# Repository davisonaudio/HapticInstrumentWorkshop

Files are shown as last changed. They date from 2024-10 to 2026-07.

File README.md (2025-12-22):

# HaptiCoupler System

This repository contaisn the design files and firmware for the HaptiCoupler system.
It also contains information for the Haptic instrument study that used the HaptiCoupler system to explore digital musical instrument designs.

More information about the system can be found in the Wiki tab of this repo.

The HaptiCoupler is a device that enables simultaneous tactile sensing and haptic feedback through a signle voice coil transducer.

This is achieved by actuating the voice coil with a voltage and sensing with current, along with some DSP running on the Teensy 4.0 to cancel the actuation signal from the sensing signal.

It is designed primarily for use with audio-driven digital resonator instruments, though can be used for other purposes.

# HapticInstrumentWorkshop
Information for the self-sensing vibrotactile haptic instrument design project. Part of the Augmented Instruments Lab at Imperial College London

For more information on using the kit and detailed documentation, visit the [wiki](https://github.com/davisonaudio/HapticInstrumentWorkshop/wiki).

Access the web control panel [here](https://davisonaudio.github.io/HapticInstrumentWorkshop/) for logging information and parameter adjustment.

# Kit Contents

- 1x Teensy 4.0 Microcontroller development board with headers
- 1x custom amplifier PCB (using MAX98789 amplifier)
- 1x Dayton Audio EX32VBDS-4 Voice Coil Transducer
- 1x 9V DC 5.1mm barrel jack power supply (centre-positive)
- 1x USB A to micro USB cable

# Getting Started
The Teensy 4.0 will come preloaded with the required firmware and mounted with its headers onto the top of the amplifier board. 

# Cloning the repo
To get a local copy of this repository (for editing the firmware or hardware files included), run the following command:
> git clone --recurse-submodules https://github.com/davisonaudio/HapticInstrumentWorkshop.git

This will clone the main repo as well as the audio-utils submodule within the firmware folder.

# Hacking the Hardware

It is unlikely that the PCB is something that we be modified as part of this study. For those with sufficient electronics knowledge, however, the design files (schematic and PCB PDFs along with KiCAD files) can be found in the hardware folder of this repo.

# Hacking the Example Software

# Hacking the Firmware
For advanced users, the firmware running on the Teensy can be modified and recompiled. All of the required files are within the firmware folder of this repo.

The firmware is developed for the Teensy using [PlatformIO](https://platformio.org). This provides more flexibility than using the Arduino IDE (as is often used with Teensy and similar boards), but still allows use of the Teensy system's wide array of useful C++ libraries. It also avoids the increased complexities of utilising a proper embedded development environment (such as NXP's MCUXpresso for the Teensy 4.0's NXP RT1060 microcontroller).

Visual Studio Code is required for PlatformIO development. For further details of development environment setup please refer to the wiki.

# Publications
For more information on related research output of this project, please refer to the below publications:

- M. Davison, C. J. Webb, M. Ducceschi and A. P. McPherson. A self-sensing haptic actuator for tactile interaction with physical modelling synthesis. *Proc. International Conference on New Interfaces for Musical Expression (NIME)*, Utrecht, Netherlands. 2024. [PDF](http://instrumentslab.org/data/andrew/davison_nime2024.pdf)

- M. Davison and A. P. McPherson. A self-sensing vibrotactile transducer for bidirectional interaction. *Proc. Eurohaptics* (work in progress), Lille, France. 2024. [PDF](http://instrumentslab.org/data/andrew/davison_eurohaptics2024.pdf)

# Contributors
This project is developed and maintained by Matt Davison. Massive thank you also to the additional contributors who helped this project happen:

- Anna Silver - CAD design of 3D printed elements
- David Gong - Initial PCB design and firmware bring-up of the amplifier board
- Prof. Andrew McPherson - Supervision and guidance throughout

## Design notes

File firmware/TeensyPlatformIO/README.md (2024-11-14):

# Self Sensing Haptic Transducer Teensy

Based on this repo: https://github.com/davisonaudio/self-sensing-haptic-transducer/tree/main
Ported from Bela to teensy

# To Use
- Set up platformio environment locally. See here for instructions: https://github.com/dsgong/max98389_teensy
- Measure the impedance of the voice coil you are using and obtain a digital filter that models the admittance response. Change these values in main.cpp.
- Upload to teensy.

# Hardware
The setup shown in this project consists of the following hardware:

- Teensy 4.0 or 4.1
- Audio amplifier with current and voltage sense feedback via i2s. I used the max98389 amplifier.
- A voice coil actuator - this project should work with many VCAs, surface transducer style VCAs (designed to turn a surface into a speaker) are what have primarily been used for testing. The default filter values correspond to a DAEX25Q-4. 
- See schematic.pdf for an example schematic

# MIDI Control

# EEPROM
The Teensy 4.0 has 1080 bytes of EEPROM memory available. This is used in this project to store tuning parameters to enable persistence after a power cycle.

The parameters are saved to EEPROM when the device receives a "Store to EEPROM" MIDI message (see MIDI documentation for more info).

The EEPROM values are loaded at the beginning of the firmware programme.

Each value is stored as a 32 bit value across 4 consecutive bytes, using little-endianness - i.e. the LSB of the value will be at EEPROM address n+0 with the MSB at address n+3.

## EEPROM Address Map

| Base Address | Parameter | Channel Num | Units | Notes |
| --- | --- | --- | ----- | ----- |
| Resonant Frequency | | 1 | | |
| Peak Gain | | 2 | | |
| Resonance Q | | 3 | | |
| Tone Level | | 4 | | |
| | | | | |
| | | | | |
| | | | | |
| | | | | |
| | | | | |
| | | | | |

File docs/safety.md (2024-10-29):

Please read the following information carefully before powering on or using the supplied hardware kit. Though the kit operates on a low voltage DC supply (5-10V, 9V when using the supplied power adapter) is it still important to adhere to basic electrical safety principles. Please keep these in mind when using the hardware kit.
# Basic Operating Procedure
- Double check any circuits before powering up the system (check for any obvious shorts or erroneously connected wires)
- Remove power from the system before making any changes to the circuitry
- Keep all elements of the hardware kit away from any liquids
- Use a 5-10V DC power supply (centre-positive) when powering the amplifier such as the provided 9V adapter. Do not use power supplies with voltages outside this range.
- Do not leave the hardware powered on while unattended
- Do not place any part of the kit on any conductive surface
- Avoid connecting headphones, or any transducer that is subsequently placed close to the ear, to the output of the amplifier to avoid sound pressure levels that exceed safe limits

# Safety Mitigations
- The amplifier IC (MAX98789) has inbuilt output short protection to prevent damage from the speaker terminals being shorted together
- The PCB has built in protection (Schottky diode) to prevent damage if a power supply with inverted polarity is plugged in
- The maximum voltage used on the board is 9V DC – no high voltages are used.
- The power supply included with the kit is CE marked and a class II mains powered device (isolated).

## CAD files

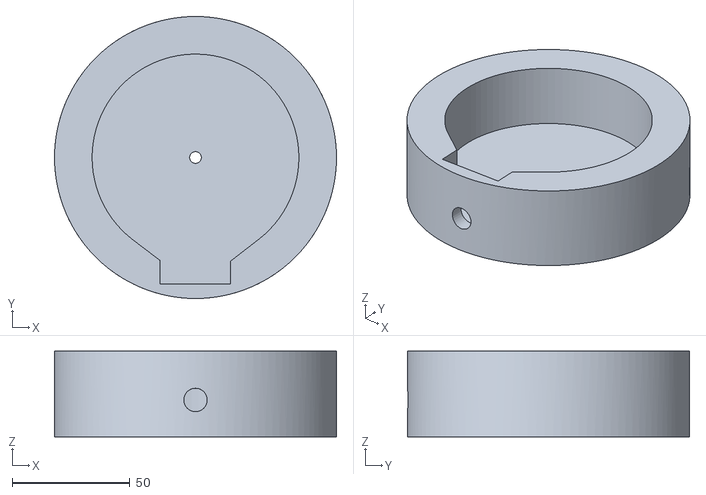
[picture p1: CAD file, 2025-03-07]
hardware/3D_printing_files/Actuator_Base.stl
120.0 x 120.0 x 36.5

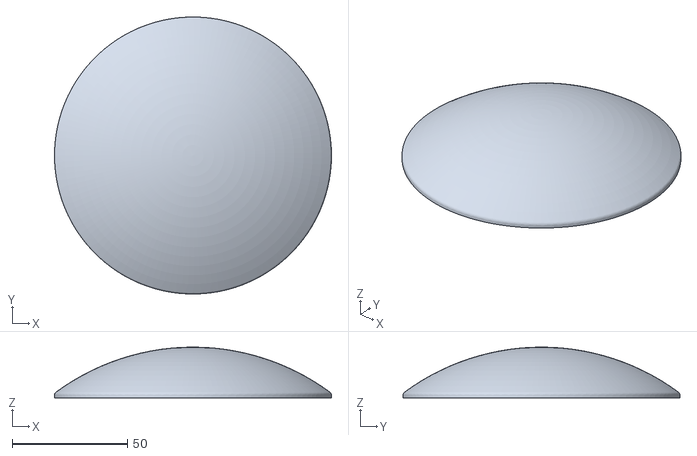
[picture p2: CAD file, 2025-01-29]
hardware/3D_printing_files/Other more niche parts/02-07_A1_ButtonTop.stl
120.0 x 120.0 x 22.0

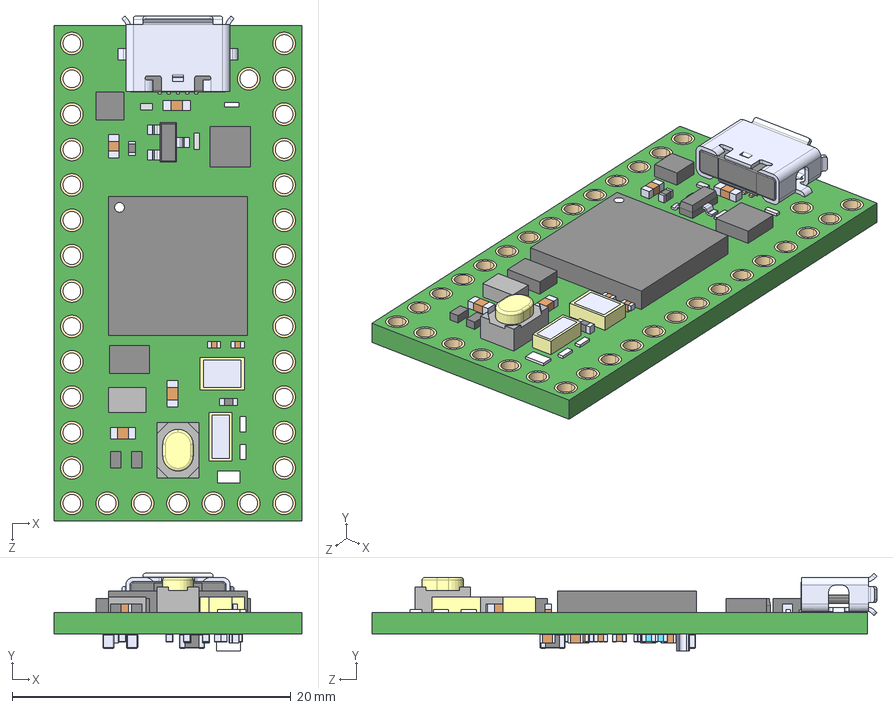
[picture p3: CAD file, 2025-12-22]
hardware/kicad_project/DEV-15583/DEV-15583.step
17.8 x 5.58 x 36.3 mm
DEV-15583 board
C5-C18 (0.55mm)
C20-C24 (0.65)
R1-R3 (0.4inch)_1269AS-H-3R3M=P2
L1^DEV-15583 ASS
C x 2
C2

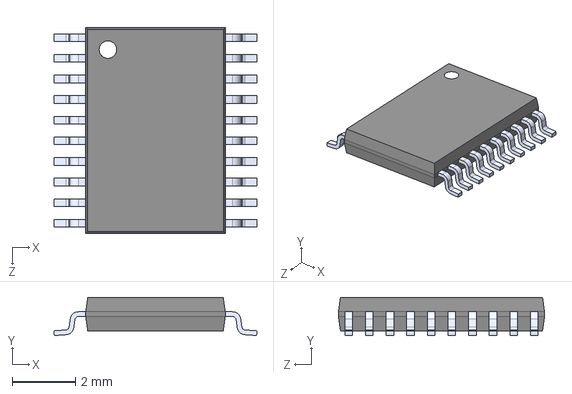
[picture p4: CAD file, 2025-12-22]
hardware/kicad_project/TXS0108EPWR/TXS0108EPWR.step
6.40 x 1.20 x 6.50 mm

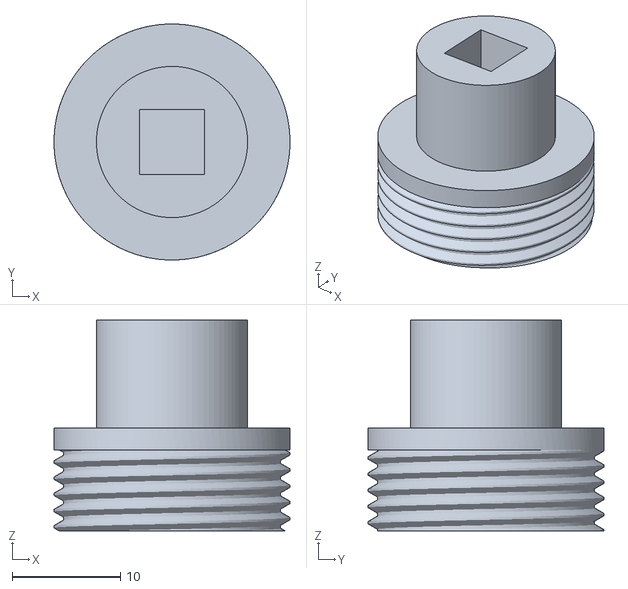
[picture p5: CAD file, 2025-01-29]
hardware/3D_printing_files/Other more niche parts/26-06_A1_universal_adapter.stl
21.8 x 21.8 x 19.5

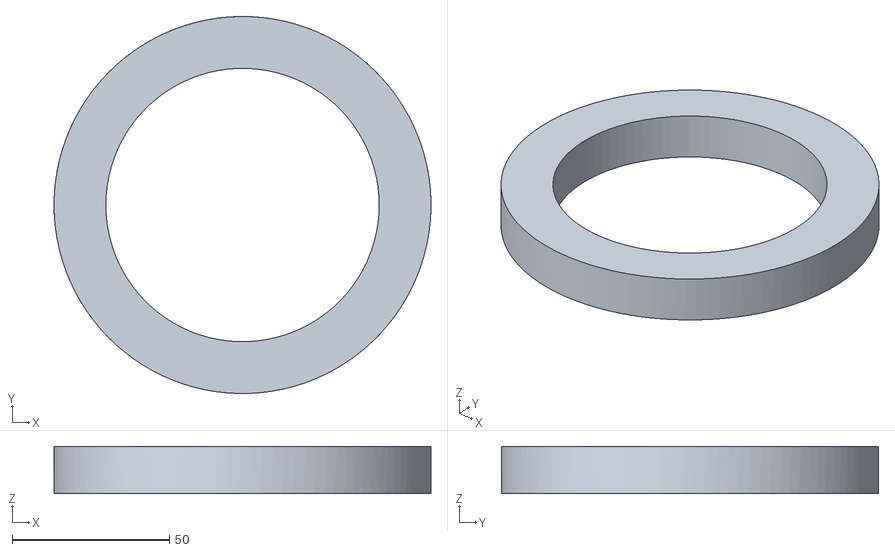
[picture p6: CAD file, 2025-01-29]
hardware/3D_printing_files/Other more niche parts/21-06_A1_SecureRing.stl
120.0 x 120.0 x 15.0

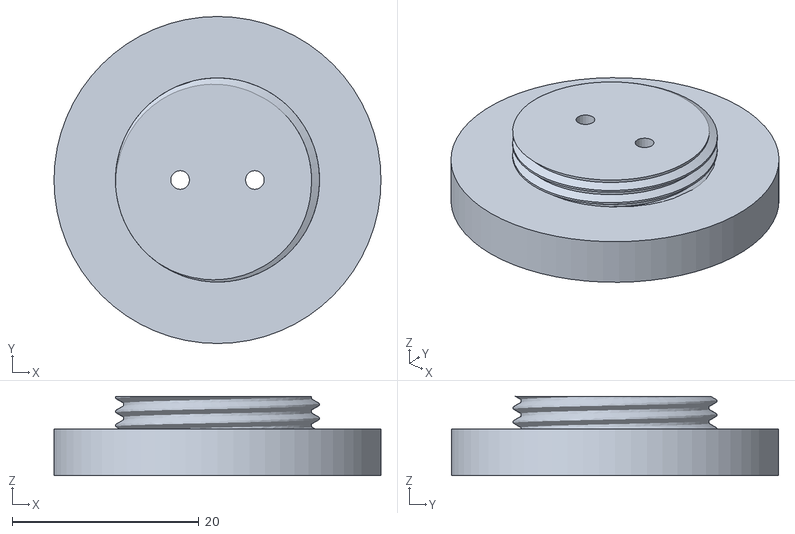
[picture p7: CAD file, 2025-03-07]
hardware/3D_printing_files/screwtop_rev_b.stl
35.0 x 35.0 x 8.50

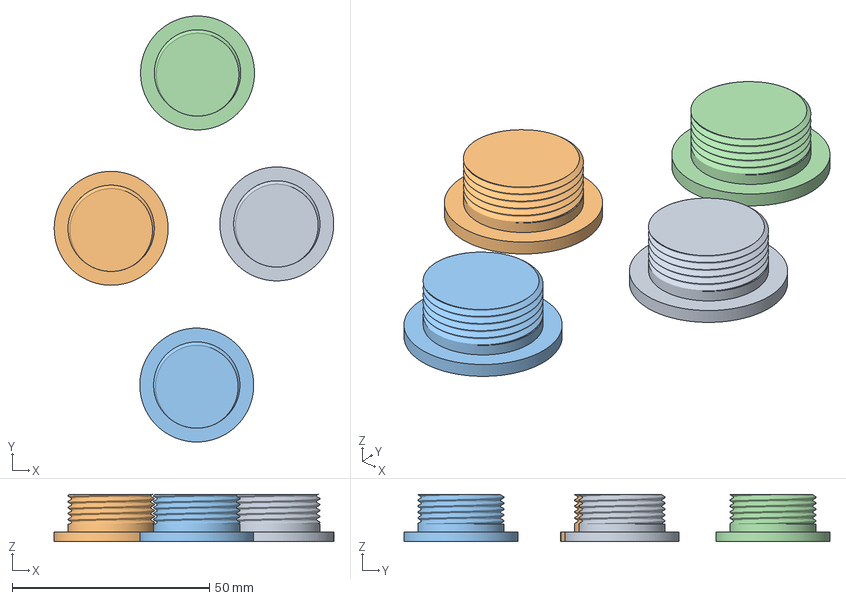
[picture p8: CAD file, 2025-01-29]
hardware/3D_printing_files/Other more niche parts/screw_top_Large_Actuator_x4.3mf
70.8 x 107.9 x 12.0 mm
screw_top_Large_Actuator.stl x 4

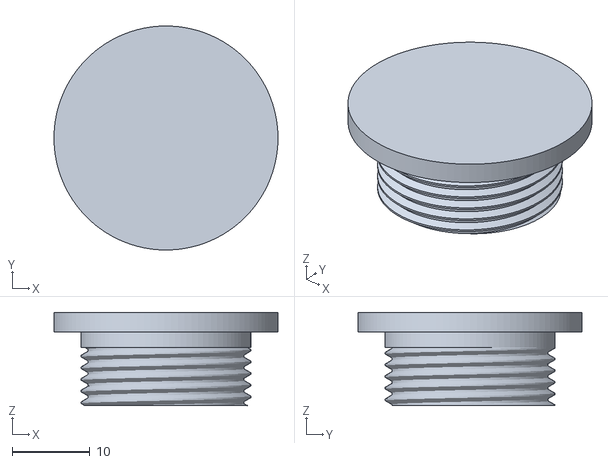
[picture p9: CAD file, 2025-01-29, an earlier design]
hardware/3D_printing_files/screwtop_rev_a.stl
28.8 x 28.8 x 12.0

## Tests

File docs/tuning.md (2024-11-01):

# Tuning

The filters used for cancellation of the actuation signal, and frequency used for damping sensing, are dependant upon the mechanical properties of the actuator.

These properties change when objects are mounted on top of the actuator (or when the actuator itself is mounted to different objects)

This may mean that the tuning parameters need adjusting after changing the mechanical properties of the instrument.

To retune the cancellation filtering, MIDI commands can be send to the device. See the midi documentation for how to do this.

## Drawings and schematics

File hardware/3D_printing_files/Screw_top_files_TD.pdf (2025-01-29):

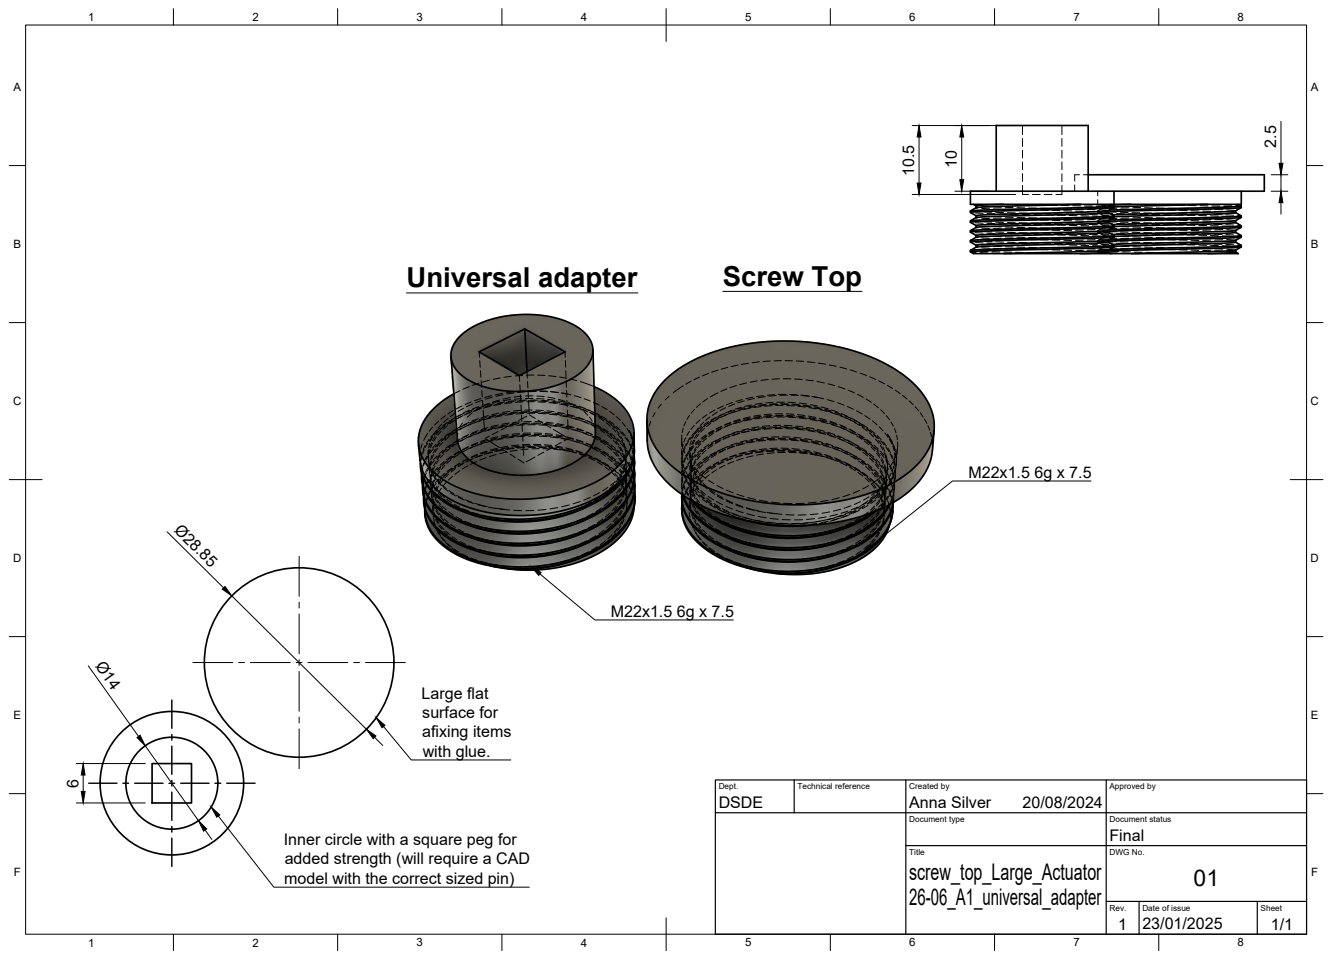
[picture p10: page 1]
Title; DWG No.; Rev.; Date of issue; Sheet; Large flat surface for afixing items with glue.; Universal adapter; Screw Top

Dept. DSDE | Technical reference | Created by Anna Silver 20/08/2024 | Approved by

Document type | Document status Final

Inner circle with a square peg for
added strength (will require a CAD
model with the correct sized pin)

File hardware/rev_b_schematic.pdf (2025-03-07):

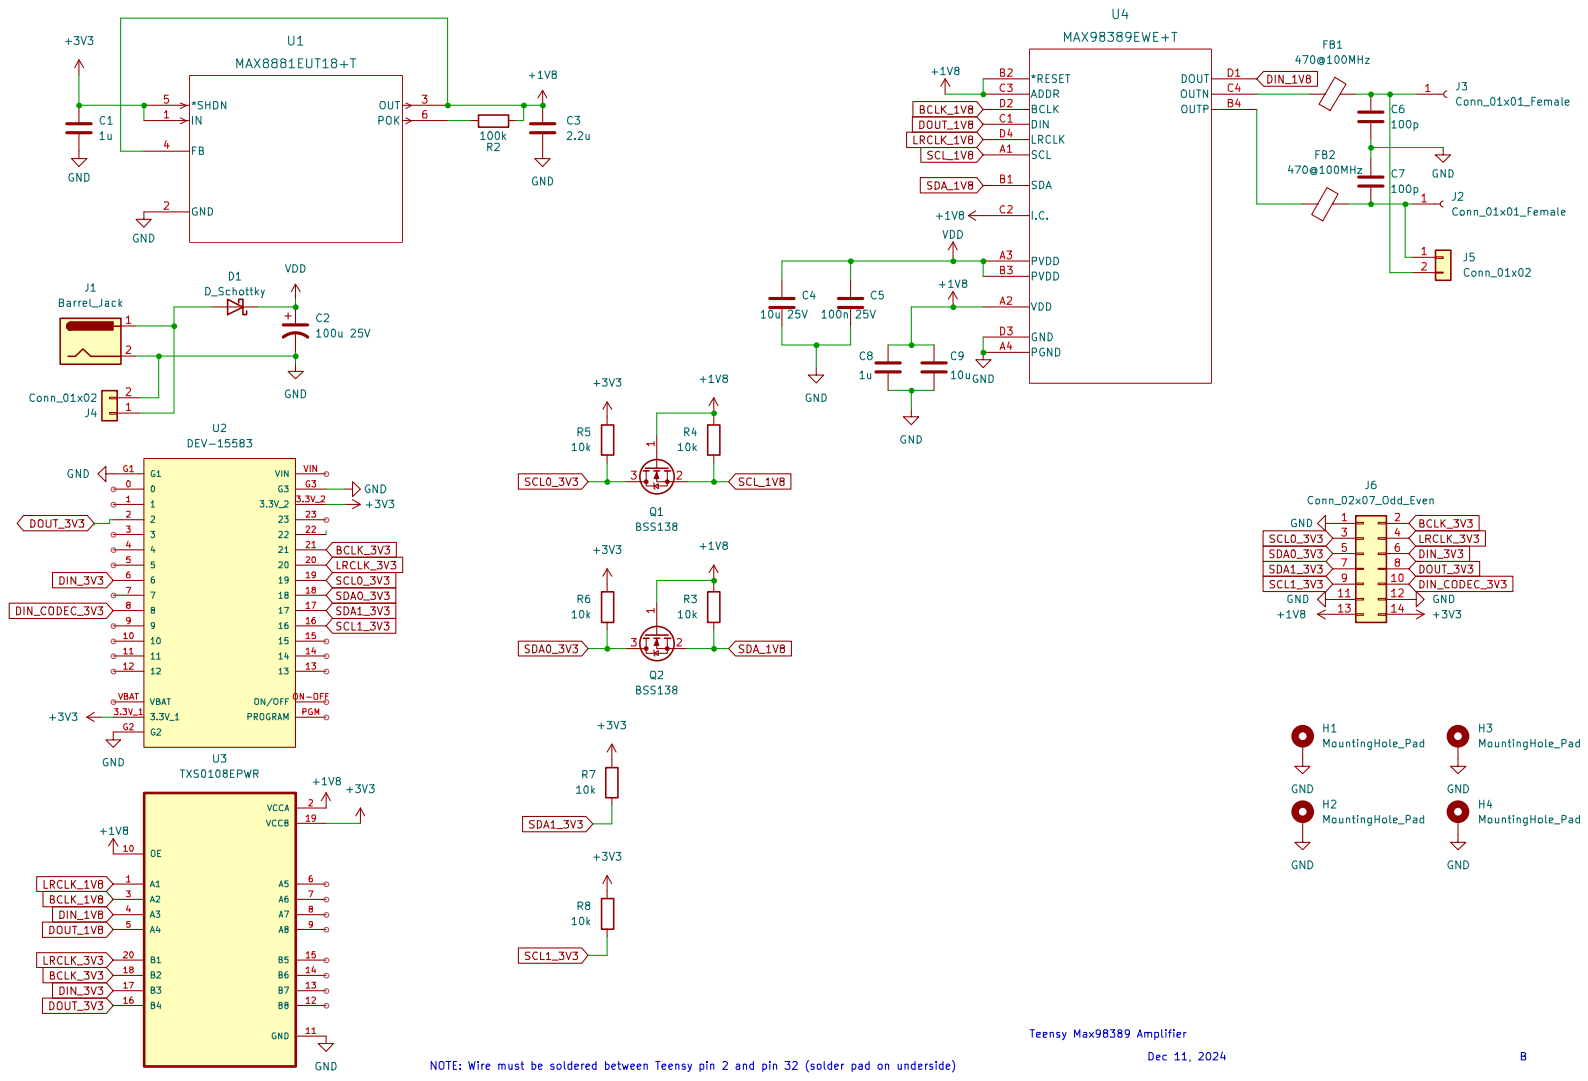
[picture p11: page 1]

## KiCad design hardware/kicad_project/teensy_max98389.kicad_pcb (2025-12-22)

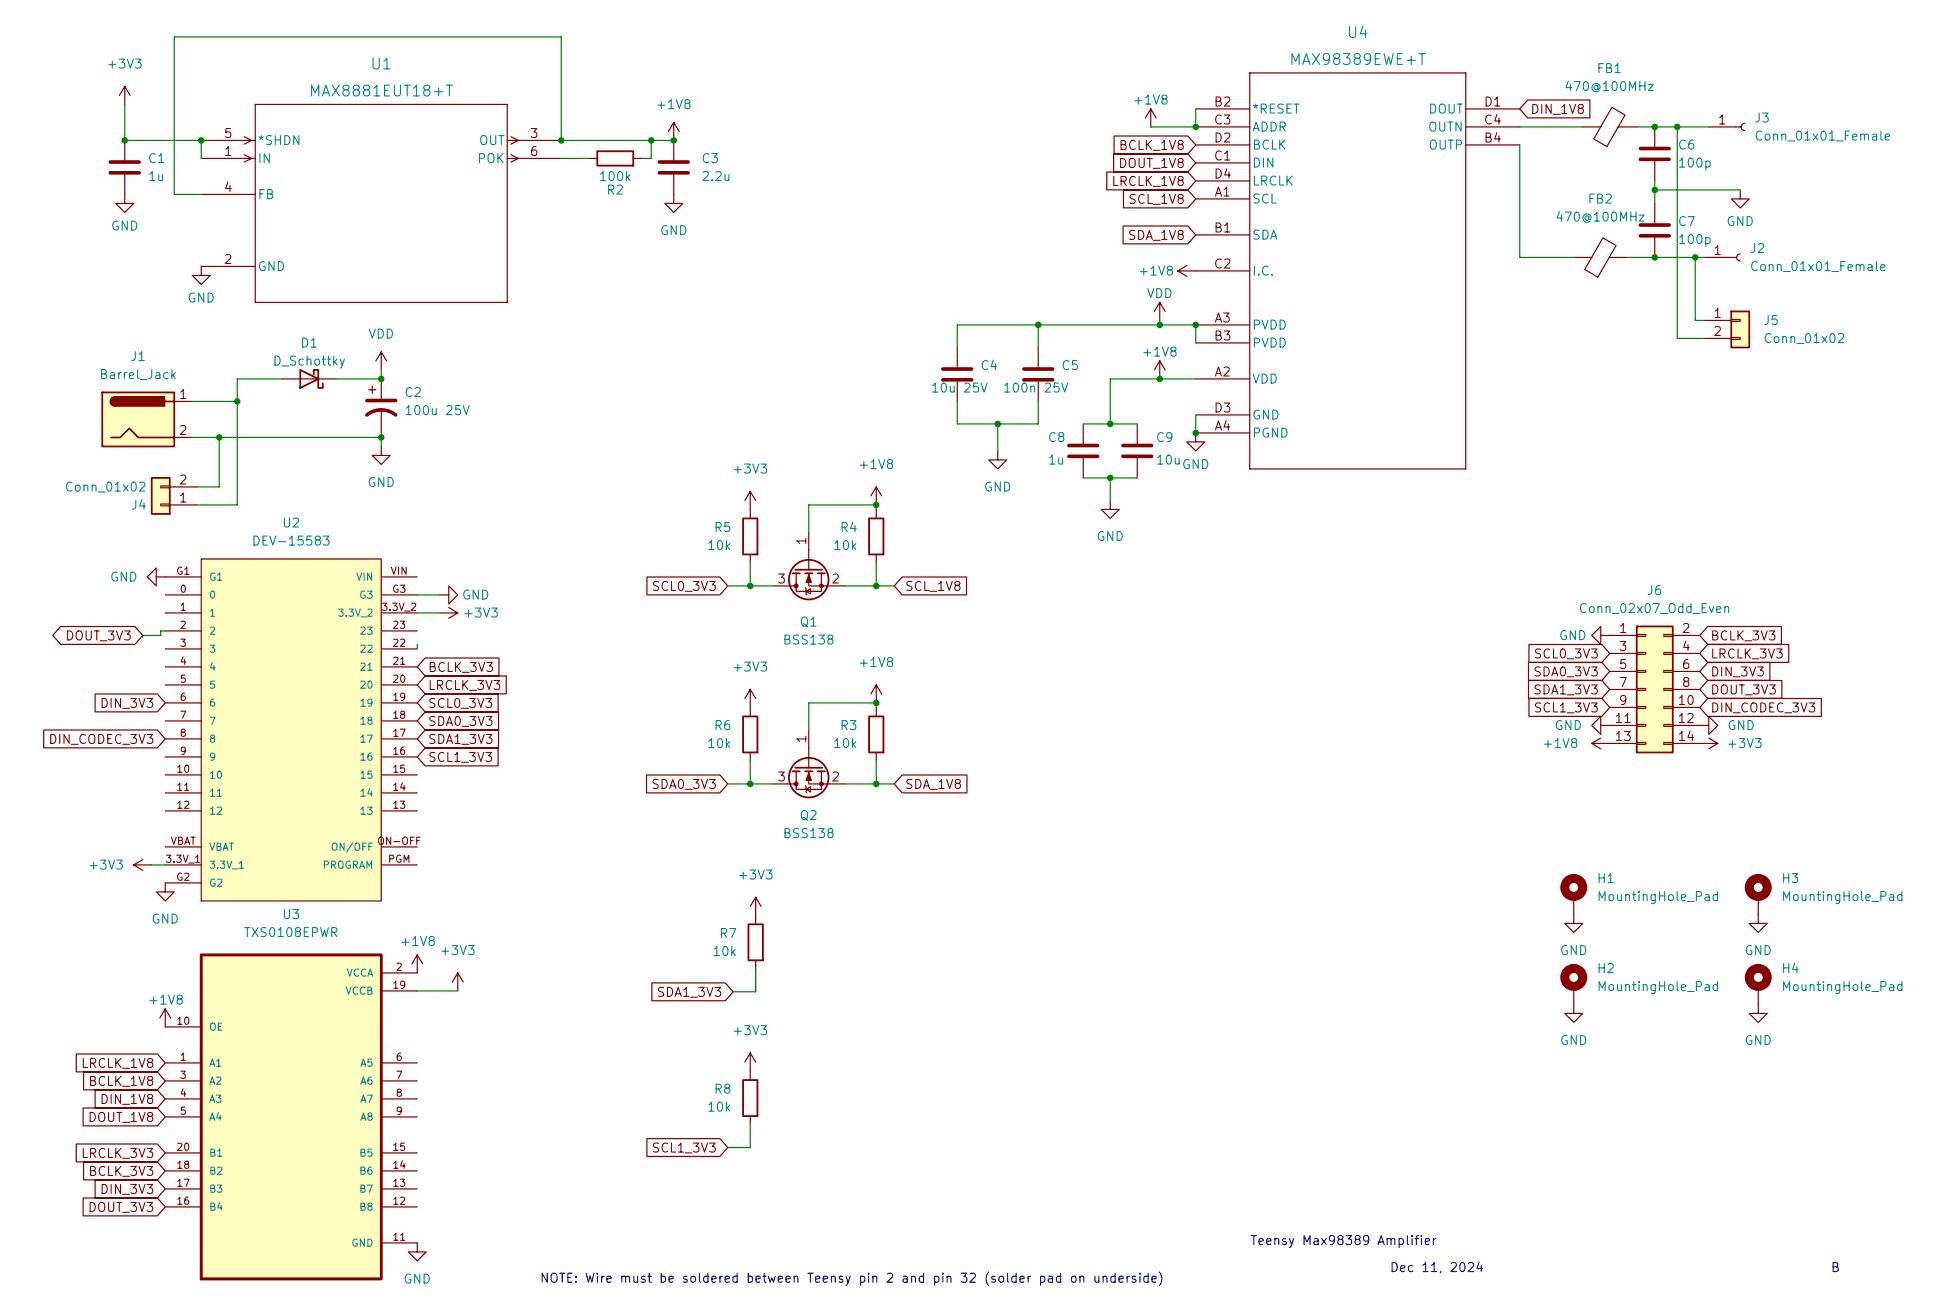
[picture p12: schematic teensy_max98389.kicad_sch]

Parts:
C1, C8: 1u; C_0603_1608Metric
C2: 100u 25V; CP_Radial_D6.3mm_P2.50mm
C3: 2.2u; C_0603_1608Metric
C4: 10u 25V; C_0603_1608Metric
C5: 100n 25V; C_0603_1608Metric
C6, C7: 100p; C_0603_1608Metric
C9: 10u; C_0603_1608Metric
D1: D_Schottky; D_0603_1608Metric
FB1, FB2: 470@100MHz; L_0805_2012Metric
H1, H2, H3, H4: MountingHole_Pad; MountingHole_3.2mm_M3_DIN965_Pad_TopBottom
J1: Barrel_Jack; BarrelJack_Kycon_KLDX-0202-xC_Horizontal
J2, J3: Conn_01x01_Female; MountingHole_6.4mm_M6_DIN965_Pad
J4, J5: Conn_01x02; Molex_KK-254_AE-6410-02A_1x02_P2.54mm_Vertical
J6: Conn_02x07_Odd_Even; PinHeader_2x07_P2.54mm_Vertical
Q1, Q2: BSS138; SOT-23
R2: 100k; R_0603_1608Metric
R3, R4, R5, R6, R7, R8: 10k; R_0603_1608Metric
U1: MAX8881EUT18+T; 21-0058I_MXM
U2: DEV-15583; MODULE_DEV-15583
U3: TXS0108EPWR; SOP65P640X120-20N
U4: MAX98389EWE+T; 21-100636_ADI

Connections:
+1V8: C3.1, C8.1, C9.1, J6.13, Q1.1 (G), Q2.1 (G), R2.2, R3.1, R4.1, U1.3 (OUT), U1.4 (FB), U3.2 (VCCA), U3.10 (OE), U4.A2 (VDD), U4.B2 (*RESET), U4.C2 (I.C.), U4.C3 (ADDR)
+3V3: C1.1, J6.14, R5.1, R6.1, R7.1, R8.1, U1.1 (IN), U1.5 (*SHDN), U2.3.3V_1, U2.3.3V_2, U3.19 (VCCB)
BCLK_1V8: U3.3 (A2), U4.D2 (BCLK)
BCLK_3V3: J6.2, U2.21, U3.18 (B2)
DIN_1V8: U3.4 (A3), U4.D1 (DOUT)
DIN_3V3: J6.6, U2.6, U3.17 (B3)
DIN_CODEC_3V3: J6.10, U2.8
DOUT_1V8: U3.5 (A4), U4.C1 (DIN)
DOUT_3V3: J6.8, U2.2, U3.16 (B4)
GND: C1.2, C2.2, C3.2, C4.2, C5.2, C6.2, C7.1, C8.2, C9.2, H1.1, H2.1, H3.1, H4.1, J1.2, J4.2, J6.1, J6.11, J6.12, U1.2 (GND), U2.G1, U2.G2, U2.G3, U3.11 (GND), U4.A4 (PGND), U4.D3 (GND)
LRCLK_1V8: U3.1 (A1), U4.D4 (LRCLK)
LRCLK_3V3: J6.4, U2.20, U3.20 (B1)
unnamed: D1.2 (A), J1.1, J4.1
unnamed: C7.2, FB2.2, J2.1, J5.1
unnamed: C6.1, FB1.2, J3.1, J5.2
unnamed: R2.1, U1.6 (POK)
unnamed: FB1.1, U4.C4 (OUTN)
unnamed: FB2.1, U4.B4 (OUTP)
SCL0_3V3: J6.3, Q1.3 (D), R5.2, U2.19
SCL1_3V3: J6.9, R8.2, U2.16
SCL_1V8: Q1.2 (S), R4.2, U4.A1 (SCL)
SDA0_3V3: J6.5, Q2.3 (D), R6.2, U2.18
SDA1_3V3: J6.7, R7.2, U2.17
SDA_1V8: Q2.2 (S), R3.2, U4.B1 (SDA)
VDD: C2.1, C4.1, C5.1, D1.1 (K), U4.A3 (PVDD), U4.B3 (PVDD)

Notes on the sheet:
Dec 11, 2024
NOTE: Wire must be soldered between Teensy pin 2 and pin 32 (solder pad on underside)
Teensy Max98389 Amplifier

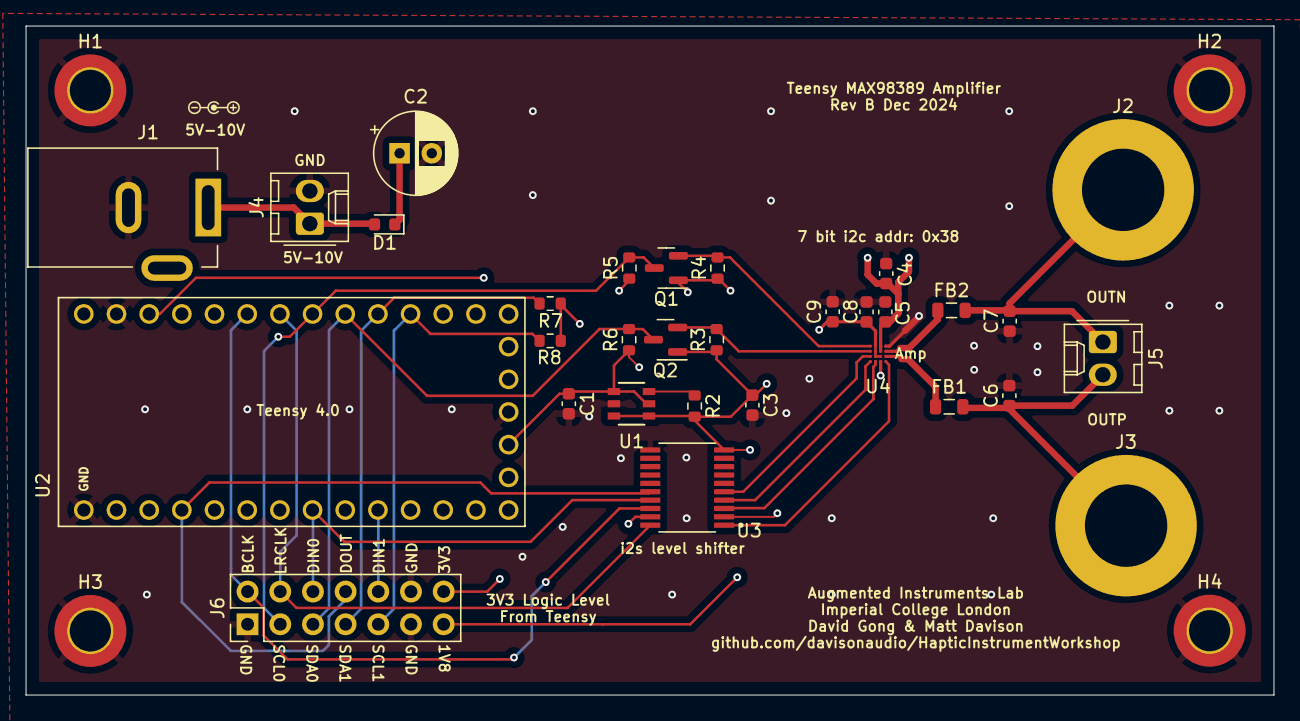
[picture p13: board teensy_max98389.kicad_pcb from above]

Board: 4 copper layers, 97.0 x 52.0 mm, 35 parts (0 on the bottom side), 25 nets.

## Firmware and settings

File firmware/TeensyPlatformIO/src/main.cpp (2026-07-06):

#include <Arduino.h>
#include <i2c_device.h>
#include "max98389.h"
#include <Audio.h>
#include <string.h>
#include <limits.h>

#include "au_Biquad.h"
#include "au_config.h"

#include "TransducerFeedbackCancellation.h"
#include "ForceSensing.h"
#include "TeensyEeprom.h"
#include "TeensySerialCommands.h"
#include "MidiComms.h"
#include "au_KarplusStrong.h"
#include "AudioRouting.h"
#include "TeensySlider.h"



//Board revision definitions (only define one):
//#define BOARD_VERSION_REV_A
#define BOARD_VERSION_REV_B



#define BUILD_RELEASE 1 //Set to 1 when generating a release build .hex file

// Write the defined serial number byte to EEPROM when flashing if enabled
// Once done, disable the write serial  to EEPROM and reflash Teensy (avoids the code writing the serial number at every startup).
#define WRITE_SERIAL_NUMBER_TO_FLASH 0
#if WRITE_SERIAL_NUMBER_TO_FLASH
#define TEENSY_SERIAL_NUMBER 12
#endif

//If enabled, this initialises the parameters stored in the EEPROM to their default values.
//Once done, this option should be disabled, the firmware recompiled and reflashed to avoid writing to the EEPROM at every startup (overwriting the existing values).
#define INITIALISE_EEPROM_VALUES 0



#define MAX_SERIAL_INPUT_CHARS 256

#if BUILD_RELEASE
static const unsigned int VERSION_MAJ = 2;
static const unsigned int VERSION_MIN = 0;
#else
//Set version number to 255.255 for debug builds to avoid confusion
static const unsigned int VERSION_MAJ = 255;
static const unsigned int VERSION_MIN = 255;
#endif

const char VERSION_NOTES[] = "Up version to 2.0. Contains lots of fixes and improvements - new audio routing modes, improved audio routing implementation, MIDI control, runtime revision detection, etc.";




IntervalTimer led_blink_timer;

bool configured = false;

char serial_input_buffer[MAX_SERIAL_INPUT_CHARS] = {0};
int input_char_index = 0;




TeensyEeprom teensy_eeprom;
uint8_t serial_number;
TeensySlider teensy_slider(&Wire1);
uint8_t slider_fw_version = 0;

//Basic error states that can occur, used for debug prints and LED blink interval.
enum class ErrorStates
{
    NORMAL_OPERATION,
    AMP_NOT_CONFIGURED,
    PLAY_BUFFER_ERROR,
    DEBUG,
    OTHER
};

ErrorStates current_error_state;

extern TransducerFeedbackCancellation::Setup AudioRouting::current_cancellation_setup;
extern ForceSensing AudioRouting::force_sensing;

static const unsigned long LED_BLINK_INTERVAL_NORMAL_OPERATION              =  1000000; //1s
static const unsigned long LED_BLINK_INTERVAL_AMP_NOT_CONFIGURED            =   500000; //500ms
static const unsigned long LED_BLINK_INTERVAL_PLAY_BUFFER_ERROR             =   250000; //250ms
static const unsigned long LED_BLINK_INTERVAL_DEBUG                         =   100000; //100ms
static const unsigned long LED_BLINK_INTERVAL_OTHER                         = 10000000; //10s


void setErrorState(ErrorStates error_state);
void printCurrentTime();
void processSerialInput(char new_char);
void blinkLED();
void readAndApplyEepromParameters();
void writeEepromParameters();
void sendSerialDetails();


// MIDI-related functions
void rxPitchChange(uint8_t channel, int pitch);
void rxProgrammeChange(uint8_t channel, uint8_t programme);
void rxControlChange(uint8_t channel, uint8_t control_number, uint8_t control_value);
void txForceSenseVal(sample_t force_sense_val);

//To reduce latency, set MAX_BUFFERS = 8 in play_queue.h and max_buffers = 8 in record_queue.h


//Pot 1 always controls actuation level, pot 2 controls headphone level


void setup() {

#if WRITE_SERIAL_NUMBER_TO_FLASH
    teensy_eeprom.write(TeensyEeprom::ByteParameters::SERIAL_NUMBER, TEENSY_SERIAL_NUMBER);
#endif

    serial_number = teensy_eeprom.read(TeensyEeprom::ByteParameters::SERIAL_NUMBER);

    // set up Teensy's built in LED
    pinMode(LED_BUILTIN, OUTPUT);
    led_blink_timer.begin(blinkLED, LED_BLINK_INTERVAL_NORMAL_OPERATION);  

    //Setup pin 2 to input due to hardware mod (pin 32 is i2s output and connected to pin 2). DO NOT USE PIN 2 AS AN OUTPUT!!
    pinMode(2, INPUT);

    printf("Teensy has booted.\r\n");
    
    

    AudioRouting::initialiseAudio();

    Wire1.begin();
    

    //Setup feedback cancellation
    AudioRouting::resetToDefaultParameters();

#if INITIALISE_EEPROM_VALUES
    writeEepromParameters();
#endif
    
    readAndApplyEepromParameters();

    printf("Resonant frequency: %f\r\n",AudioRouting::current_cancellation_setup.resonant_frequency_hz);

    usbMIDI.setHandlePitchChange(rxPitchChange);
    usbMIDI.setHandleProgramChange(rxProgrammeChange);
    usbMIDI.setHandleControlChange(rxControlChange);

    sendSerialDetails();

    
}


unsigned long total_sample_count = 0;

unsigned long user_controls_time = 0;

void loop() {

    if (AudioRouting::force_sensing.valueAvailable())
    {
        txForceSenseVal(AudioRouting::force_sensing.getDamping());
        //printf("Force sense: %f\r\n",AudioRouting::force_sensing.getDamping());
        teensy_slider.setLedBar(AudioRouting::force_sensing.getDamping() * 10, 100, true);
    }

    //Process USB Serial input (debugging)
    while (Serial.available()) {
        char new_char = Serial.read();
        processSerialInput(new_char);
    }

    //Process USB MIDI input (configuring parameters)
    usbMIDI.read();

    if (user_controls_time < (millis() - 30))
    {
        int pot_val = teensy_slider.readPot(5);
        //printf("Pot: %d\r\n", pot_val);
        //AudioRouting::setActuationLevel(pot_val - 127.0);
        // printf("Pot 1 value: %d \r\n",teensy_slider.readPot(1));
        // delayMicroseconds(300);
        // printf("Switch 0: %d \r\n",teensy_slider.getSwitchPressCount(0));
        // delayMicroseconds(300);
        // static uint8_t led_num = 0;
        // teensy_slider.setLedBrightness(led_num, 0);
        // led_num = (led_num + 1) % 10;
        // delayMicroseconds(300);
        // teensy_slider.setLedBrightness(led_num, 255);
        
        user_controls_time = millis();
    }
}

void setErrorState(ErrorStates error_state)
{
    current_error_state = error_state;
    printCurrentTime();
    switch (error_state)
    {
    case ErrorStates::NORMAL_OPERATION:
        printf(" Entering normal operation.\r\n");
        led_blink_timer.update(LED_BLINK_INTERVAL_NORMAL_OPERATION);
        break;

    case ErrorStates::AMP_NOT_CONFIGURED:
        printf(" Error occurred while attempting to configure the MAX98389 chip via i2c. Check whether Teensy is connected to the board correctly.\r\n");
        led_blink_timer.update(LED_BLINK_INTERVAL_AMP_NOT_CONFIGURED);
        break;
    
    case ErrorStates::PLAY_BUFFER_ERROR:
        printf(" Error occured while playing output buffer queue.\r\n");
        led_blink_timer.update(LED_BLINK_INTERVAL_PLAY_BUFFER_ERROR);
        break;

    case ErrorStates::OTHER:
        printf(" Other (generic) error occurred.\r\n");
        led_blink_timer.update(LED_BLINK_INTERVAL_OTHER);
        break;

    case ErrorStates::DEBUG:
        printf(" Entered debug mode.\r\n");
        led_blink_timer.update(LED_BLINK_INTERVAL_DEBUG);
        AudioRouting::setAudioShieldMode(AudioRouting::AudioShieldMode::DEBUG);
        break;
    
    default:
        printf(" Unknown error occurred.\r\n");
        led_blink_timer.update(LED_BLINK_INTERVAL_OTHER);
        break;
    }
}

void printCurrentTime()
{
    int time_s = millis() / 1000;
    int hours = time_s / 3600;
    int minutes = (time_s - (hours * 3600)) / 60;
    int seconds = time_s - (hours * 3600) - (minutes * 60);  
    printf("%02d:%02d:%02d", hours, minutes, seconds);
}

void readAndApplyEepromParameters()
{

    sample_t rounded_freq = AudioRouting::force_sensing.setResonantFrequencyHz(teensy_eeprom.read(TeensyEeprom::FloatParameters::RESONANT_FREQUENCY_HZ));
    AudioRouting::force_sensing.setWindowSizePeriods(teensy_eeprom.read(TeensyEeprom::ByteParameters::GOERTZEL_WINDOW_LENGTH));
    AudioRouting::force_sensing.setRawDampedValue(teensy_eeprom.read(TeensyEeprom::FloatParameters::DAMPED_CALIBRATION_VALUE));
    AudioRouting::force_sensing.setRawUndampedValue(teensy_eeprom.read(TeensyEeprom::FloatParameters::UNDAMPED_CALIBRATION_VALUE));

    AudioRouting::current_cancellation_setup.resonant_frequency_hz = rounded_freq;
    AudioRouting::current_cancellation_setup.resonance_peak_gain_db = teensy_eeprom.read(TeensyEeprom::FloatParameters::RESONANT_GAIN_DB);
    AudioRouting::current_cancellation_setup.resonance_q = teensy_eeprom.read(TeensyEeprom::FloatParameters::RESONANT_Q);
    AudioRouting::current_cancellation_setup.resonance_tone_level_db =  teensy_eeprom.read(TeensyEeprom::FloatParameters::TONE_LEVEL_DB);
    AudioRouting::current_cancellation_setup.inductance_filter_coefficient =  teensy_eeprom.read(TeensyEeprom::FloatParameters::INDUCTANCE_FILTER_COEFFICIENT);
    AudioRouting::current_cancellation_setup.transducer_input_wideband_gain_db =  teensy_eeprom.read(TeensyEeprom::FloatParameters::BROADBAND_GAIN_DB);
    AudioRouting::current_cancellation_setup.sample_rate_hz = AUDIO_SAMPLE_RATE_EXACT;
    AudioRouting::current_cancellation_setup.amplifier_type = TransducerFeedbackCancellation::AmplifierType::CURRENT_DRIVE;
    AudioRouting::current_cancellation_setup.lowpass_transducer_io = true;
    AudioRouting::current_cancellation_setup.output_to_transducer_lpf_cutoff_hz = teensy_eeprom.read(TeensyEeprom::FloatParameters::OUTPUT_LPF_CUTOFF_HZ);
    AudioRouting::current_cancellation_setup.input_from_transducer_lpf_cutoff_hz = teensy_eeprom.read(TeensyEeprom::FloatParameters::INPUT_LPF_CUTOFF_HZ);
    AudioRouting::current_cancellation_setup.inductance_coefficients = teensy_eeprom.readInductanceBiquad();
    AudioRouting::transducer_processing.setup(AudioRouting::current_cancellation_setup);

    AudioRouting::setBoardRevision(teensy_eeprom.readBoardRevision());



    AudioRouting::setHeadphoneLevel(teensy_eeprom.read(TeensyEeprom::FloatParameters::HEADPHONE_LEVEL_DB));
    AudioRouting::setActuationLevel(teensy_eeprom.read(TeensyEeprom::FloatParameters::ACTUATION_LEVEL_DB));

    AudioRouting::setAudioShieldMode(teensy_eeprom.readAudioShieldMode());

    uint8_t stored_maj_version = teensy_eeprom.read(TeensyEeprom::ByteParameters::LAST_SAVED_MAJ_VERSION);
    uint8_t stored_min_version = teensy_eeprom.read(TeensyEeprom::ByteParameters::LAST_SAVED_MIN_VERSION);


    printf("Read parameters from flash. Parameters were stored in V%d.%d. Resonant frequency now: %f\r\n",stored_maj_version, stored_min_version, AudioRouting::current_cancellation_setup.resonant_frequency_hz);
    

}

/*
 * Write the current parameters into the flash
 */
void writeEepromParameters()
{
    teensy_eeprom.write(TeensyEeprom::FloatParameters::RESONANT_FREQUENCY_HZ, AudioRouting::current_cancellation_setup.resonant_frequency_hz);
    teensy_eeprom.write(TeensyEeprom::FloatParameters::RESONANT_GAIN_DB, AudioRouting::current_cancellation_setup.resonance_peak_gain_db);
    teensy_eeprom.write(TeensyEeprom::FloatParameters::RESONANT_Q, AudioRouting::current_cancellation_setup.resonance_q);
    teensy_eeprom.write(TeensyEeprom::FloatParameters::TONE_LEVEL_DB, AudioRouting::current_cancellation_setup.resonance_tone_level_db);
    teensy_eeprom.write(TeensyEeprom::FloatParameters::INDUCTANCE_FILTER_COEFFICIENT, AudioRouting::current_cancellation_setup.inductance_filter_coefficient);
    teensy_eeprom.write(TeensyEeprom::FloatParameters::BROADBAND_GAIN_DB, AudioRouting::current_cancellation_setup.transducer_input_wideband_gain_db);
    teensy_eeprom.write(TeensyEeprom::FloatParameters::DAMPED_CALIBRATION_VALUE, AudioRouting::force_sensing.getRawDampedValue());
    teensy_eeprom.write(TeensyEeprom::FloatParameters::UNDAMPED_CALIBRATION_VALUE, AudioRouting::force_sensing.getRawUndampedValue());
    teensy_eeprom.write(TeensyEeprom::FloatParameters::OUTPUT_LPF_CUTOFF_HZ, AudioRouting::current_cancellation_setup.output_to_transducer_lpf_cutoff_hz);
    teensy_eeprom.write(TeensyEeprom::FloatParameters::INPUT_LPF_CUTOFF_HZ, AudioRouting::current_cancellation_setup.input_from_transducer_lpf_cutoff_hz);

    teensy_eeprom.write(TeensyEeprom::FloatParameters::HEADPHONE_LEVEL_DB, AudioRouting::getHeadphoneLevel());
    teensy_eeprom.write(TeensyEeprom::FloatParameters::ACTUATION_LEVEL_DB, AudioRouting::getActuationLevel());

    teensy_eeprom.write(TeensyEeprom::ByteParameters::GOERTZEL_WINDOW_LENGTH, AudioRouting::force_sensing.getWindowSizePeriods());
    teensy_eeprom.write(TeensyEeprom::ByteParameters::LAST_SAVED_MAJ_VERSION, VERSION_MAJ);
    teensy_eeprom.write(TeensyEeprom::ByteParameters::LAST_SAVED_MIN_VERSION, VERSION_MIN);
    teensy_eeprom.writeInductanceBiquad(AudioRouting::current_cancellation_setup.inductance_coefficients);
    teensy_eeprom.writeBoardRevision(AudioRouting::BoardRevision::REV_B);
    teensy_eeprom.writeAudioShieldMode(AudioRouting::getAudioShieldMode());
    printCurrentTime();
    printf(" Parameters saved to EEPROM.\r\n");
}


/*
 * Parse serial character input (parses on newline '\n')
 */
void processSerialInput(char new_char)
{
    if (input_char_index == (MAX_SERIAL_INPUT_CHARS - 1))
    {
        printf("Error! Max number of serial input characters (%d) per line exceeded. Input buffer reset.\r\n",MAX_SERIAL_INPUT_CHARS);
        input_char_index = 0;
        return;
    }

    serial_input_buffer[input_char_index++] = new_char;
    if (new_char == '\n')
    {

        char* parameter_arg = strtok(serial_input_buffer, " "); //Split input string on space
        char* value_arg = strtok(NULL, " ");

        if (!strncmp(parameter_arg, SerialCommands::kDebugModeString, strlen(SerialCommands::kDebugModeString)))
        {
            setErrorState(ErrorStates::DEBUG);
        }
        else if (!strncmp(parameter_arg, SerialCommands::kNormalModeString, strlen(SerialCommands::kNormalModeString)))
        {
            setErrorState(ErrorStates::NORMAL_OPERATION);
            AudioRouting::setAudioShieldMode(AudioRouting::AudioShieldMode::HEADPHONE_OUTPUT);
        }
        else if (!strncmp(parameter_arg, SerialCommands::kStandaloneSynthModeString, strlen(SerialCommands::kStandaloneSynthModeString)))
        {
            AudioRouting::setAudioShieldMode(AudioRouting::AudioShieldMode::STANDALONE_SYNTH);
            printf("Karplus strong synth enabled\r\n");
        }
        else if (!strncmp(parameter_arg, SerialCommands::kLoopbackTestModeString, strlen(SerialCommands::kLoopbackTestModeString)))
        {
            AudioRouting::setAudioShieldMode(AudioRouting::AudioShieldMode::LOOPBACK_TEST);
            printf("Loopback Test mode enabled\r\n");
        }
        else if (!strncmp(parameter_arg, SerialCommands::kPiezoModeString, strlen(SerialCommands::kPiezoModeString)))
        {
            AudioRouting::setAudioShieldMode(AudioRouting::AudioShieldMode::HP_OP_PIEZO_IP);
            printf("Piezo mode enabled\r\n");
        }
        else if (!strncmp(parameter_arg, SerialCommands::kResetParametersString, strlen(SerialCommands::kResetParametersString)))
        {
            AudioRouting::resetToDefaultParameters();
        }
        else if (!strncmp(parameter_arg, SerialCommands::kSaveToEepromString, strlen(SerialCommands::kSaveToEepromString)))
        {
            writeEepromParameters();
        }
        else if (!strncmp(parameter_arg, SerialCommands::kHelpString, strlen(SerialCommands::kHelpString)))
        {
            printSerialHelp();
        }
        else if (!strncmp(parameter_arg, SerialCommands::kCalibrateDamped, strlen(SerialCommands::kCalibrateDamped)))
        {
            AudioRouting::force_sensing.calibrateDamped();
        }
        else if (!strncmp(parameter_arg, SerialCommands::kCalibrateUndamped, strlen(SerialCommands::kCalibrateUndamped)))
        {
            AudioRouting::force_sensing.calibrateUndamped();
        }
        else if (!strncmp(parameter_arg, SerialCommands::kInfoString, strlen(SerialCommands::kInfoString)))
        {
            sendSerialDetails();
        }
        
        else
        { //Check for arguments that have value parameters
            

                        //Check for resonant frequency command
            if (!strncmp(parameter_arg, SerialCommands::kModeString, strlen(SerialCommands::kModeString)))
            {
                if (value_arg)
                { //Set the resonant frequency to the provided value
                    AudioRouting::setAudioShieldMode(static_cast<AudioRouting::AudioShieldMode>(atoi(value_arg)));
                }
                else
                { //If value_arg = NULL then no value provided, return current mode
                    printf("%d\n", static_cast<int>(AudioRouting::getAudioShieldMode()));
                }
            }

            //Check for resonant frequency command
            if (!strncmp(parameter_arg, SerialCommands::kResonantFreqString, strlen(SerialCommands::kResonantFreqString)))
            {
                if (value_arg)
                { //Set the resonant frequency to the provided value
                    AudioRouting::setResonantFrequency(atof(value_arg));
                    printf("Resonant frequency set to: %fHz\r\n", atof(value_arg));
                }
                else
                { //If value_arg = NULL then no value provided, return current value
                    printf("%f\n", AudioRouting::current_cancellation_setup.resonant_frequency_hz);
                }
            }

            //Check for tone level command
            else if (!strncmp(parameter_arg, SerialCommands::kToneLevelString, strlen(SerialCommands::kToneLevelString)))
            {
                if (value_arg)
                { //Set the resonant frequency to the provided value
                    AudioRouting::setToneLevel(atof(value_arg));
                    printf("Tone level set to: %fdB\r\n", atof(value_arg));
                }
                else
                { //If value_arg = NULL then no value provided, return current value
                    printf("%f\n", AudioRouting::current_cancellation_setup.resonance_tone_level_db);
                }
            }


            //Check for resonance q command
            else if (!strncmp(parameter_arg, SerialCommands::kResonantQString, strlen(SerialCommands::kResonantQString)))
            {
                if (value_arg)
                { //Set the resonance q to the provided value
                    AudioRouting::setResonanceQ(atof(value_arg));
                    printf("Resonance q set to: %f\r\n", atof(value_arg));
                }
                else
                { //If value_arg = NULL then no value provided, return current value
                    printf("%f\n", AudioRouting::current_cancellation_setup.resonance_q);
                }
            }

            //Check for resonance gain command
            else if (!strncmp(parameter_arg, SerialCommands::kResonantGainString, strlen(SerialCommands::kResonantGainString)))
            {
                if (value_arg)
                { //Set the resonance q to the provided value
                    AudioRouting::setResonanceGain(atof(value_arg));
                    printf("Resonance gain set to: %fdB\r\n", atof(value_arg));
                }
                else
                { //If value_arg = NULL then no value provided, return current value
                    printf("%f\n", AudioRouting::current_cancellation_setup.resonance_peak_gain_db);
                }
            }

            //Check for wideband gain command
            else if (!strncmp(parameter_arg, SerialCommands::kWidebandGainString, strlen(SerialCommands::kWidebandGainString)))
            {
                if (value_arg)
                { //Set the resonance q to the provided value
                    AudioRouting::setWidebandGain(atof(value_arg));
                    printf("Wideband gain set to: %fdB\r\n", atof(value_arg));
                }
                else
                { //If value_arg = NULL then no value provided, return current value
                    printf("%f\n", AudioRouting::current_cancellation_setup.transducer_input_wideband_gain_db);
                }
            }

            //Check for output lowpass cutoff command
            else if (!strncmp(parameter_arg, SerialCommands::kLowpassOutputFreq, strlen(SerialCommands::kLowpassOutputFreq)))
            {
                if (value_arg)
                { //Set the resonance q to the provided value
                    AudioRouting::setOutputLowpassFc(atof(value_arg));
                    printf("Output lowpass cutoff frequency set to: %fHz\r\n", atof(value_arg));
                }
                else
                { //If value_arg = NULL then no value provided, return current value
                    printf("%f\n", AudioRouting::current_cancellation_setup.output_to_transducer_lpf_cutoff_hz);
                }
            }

            //Check for wideband gain command
            else if (!strncmp(parameter_arg, SerialCommands::kLowpassInputFreq, strlen(SerialCommands::kLowpassInputFreq)))
            {
                if (value_arg)
                { //Set the resonance q to the provided value
                    AudioRouting::setInputLowpassFc(atof(value_arg));
                    printf("Input lowpass cutoff frequency set to: %fHz\r\n", atof(value_arg));
                }
                else
                { //If value_arg = NULL then no value provided, return current value
                    printf("%f\n", AudioRouting::current_cancellation_setup.input_from_transducer_lpf_cutoff_hz);
                }
            }
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

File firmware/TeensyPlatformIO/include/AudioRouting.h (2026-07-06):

/*
 
AudioRouting.h
 
Author: Matt Davison
Date: 13/06/2025
 
*/

#pragma once

#include <Audio.h>
#include "max98389.h"
#include <Arduino.h>
#include "au_config.h"
#include "TransducerFeedbackCancellation.h"
#include "au_KarplusStrong.h"
#include "ForceSensing.h"

#define teensy_sample_t int16_t
#define RESONANT_FREQ_HZ 89.0

#define BOARD_VERSION_REV_B

namespace AudioRouting {


AudioInputI2SQuad        i2s_quad_in;
AudioInputUSB            usb_in;
AudioInputAnalog         adc_input(A0);

AudioOutputI2SQuad       i2s_quad_out;
AudioOutputUSB           usb_out;


AudioControlSGTL5000     audio_shield;


TransducerFeedbackCancellation transducer_processing;
TransducerFeedbackCancellation::Setup current_cancellation_setup;
ForceSensing force_sensing;
AudioUtils::KarplusStrong kp_synth;
sample_t headphone_level_db = 0.0;
sample_t actuation_level_db = 0.0;


enum class AudioShieldMode
{
    DISCONNECTED = 0, //No audio shield, function as normal to/from USB audio connection
    HEADPHONE_OUTPUT, //Actuation signal also output to headphones (without lowpass applied)
    HP_OP_PIEZO_IP,   //Same as HEADPHONE_OUTPUT but audio input is highpassed and mixed with current return for excitation input (for additional piezo)
    ANALOG_ONLY,      //Audio shield replaces USB connection - audio in is sent to actuation amplifier and current return send to audio out
    STANDALONE_SYNTH,  //No external synth required. Inbuilt resonant synthesis models used and output over headphones.
    LOOPBACK_TEST,    //Loops back usb to usb and analog in to analog out
    DEBUG,
    ACCELEROMETER,     //Outputs current and ADC input (accelerometer) to USB
    COMPARE            //Left channel = cancelled, right = raw current
};
AudioShieldMode audio_shield_mode;
bool audio_shield_connected = false;
bool max_amp_configured = false;

enum class BoardRevision
{ //Amplifier PCB revision (affects i2s pin assignment)
    REV_A = 0,
    REV_B
};
BoardRevision board_rev = BoardRevision::REV_B;


class AudioRouter : public AudioStream
{
public:
        static constexpr int NUM_INPUTS = 7;
        static constexpr int NUM_OUTPUTS = 5;
        enum class RouterInputs
        {
            AMP_CURRENT,
            AMP_VOLTAGE,
            USB_L,
            USB_R,
            ANALOG_L,
            ANALOG_R,
            ADC
        };
        enum class RouterOutputs
        {
            AMP,
            USB_L,
            USB_R,
            ANALOG_L,
            ANALOG_R
        };        
        AudioRouter() : AudioStream(NUM_INPUTS, inputQueueArray) {
          // any extra initialization
        }
        void update(void){

            //Receive new input buffers for each inputs
            for (int i = 0 ; i < NUM_INPUTS ; i++)
            {
                current_input_queues[i] = receiveWritable(i);
            }

            for (int i = 0 ; i < NUM_OUTPUTS ; i++)
            {
                current_output_queues[i] = allocate();
            }

            /*
             * Process audio here
             */
            //Get User's USB volume setting
            float volume_level = usb_in.volume(); //0.0 - 1.0

            //Loop through each sample in the buffers
            for (int i = 0; i < AUDIO_BLOCK_SAMPLES; i++) {   

                //Convert all incoming samples from int16 to normalised float
                sample_t usb_in_l = getSample(RouterInputs::USB_L, i);
                sample_t usb_in_r = getSample(RouterInputs::USB_R, i);
                sample_t amp_in_voltage = getSample(RouterInputs::AMP_VOLTAGE, i);
                sample_t amp_in_current = getSample(RouterInputs::AMP_CURRENT, i);
                sample_t analog_in_l = getSample(RouterInputs::ANALOG_L, i);
                sample_t analog_in_r = getSample(RouterInputs::ANALOG_R, i);
                sample_t adc_in = getSample(RouterInputs::ADC, i);

                //Apply volume level (simple linear scaling currently - could be improved)
                usb_in_l *= volume_level;
                usb_in_r *= volume_level;

                //Cancel actuation signal from sensed signal
                TransducerFeedbackCancellation::UnprocessedSamples unprocessed;
                unprocessed.output_to_transducer = usb_in_l;
                unprocessed.input_from_transducer = amp_in_current; //Current measurement from amp
                unprocessed.reference_input_loopback = amp_in_voltage; //Voltage measurement from amp
                TransducerFeedbackCancellation::ProcessedSamples processed = transducer_processing.process(unprocessed);

                sample_t usb_out_l, usb_out_r, amp_out, analog_out_l, analog_out_r;
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

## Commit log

2024-10-29 Added firmware, safety doc, schematic pdf
2024-11-04 Fixed firmware build error with audio utils
    [TransducerFeedbackCancellation.h]
2024-12-01 FIRMWARE: Added force sense debug print option
2025-01-28 Added 3D printing files
    [02-07_A1_ButtonTop.stl, 21-06_A1_SecureRing.stl, 26-06_A1_universal_adapter.stl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]
2025-02-03 FIRMWARE: Added midi control of calibration, resonant freq and eeprom write
2025-02-08 Changed website js layout, fixed normalisedToInt bug in audio-utils
    [main.cpp]
2025-02-08 Added MIDI command to reset parameters to compiled defaults in firmware.
    [main.cpp]
2025-02-09 Implemented control of resonant frequency via pitch bend channel 0
2025-02-13 Updated actuator base STL file
    [Actuator_Base.stl, Base_Large_actuator.stl]
2025-02-19 Added smoothing filter for force sensing values, added storing and recalling force sense calibration in EEPROM, added resonant filter for actuation signal
2025-03-06 Added rev B schematic
2025-03-06 Added new screwtop CAD file
    [screwtop_rev_a.stl, screwtop_rev_b.stl]
2025-03-07 Added board revision to EEPROM - not yet used
2025-03-10 Implemented serial control of resonant q, resonant gain, wideband gain, and reading of current values
2025-03-10 Added calibrate damped/undamped serial commands and recall last input on serial website interface
2025-05-21 Fixed text on serial monitor
    [main.cpp]
2025-06-02 Initial audio board development
2025-06-19 Moved audio code to own AudioRouter file, added initial development for interfacing with the control board
2025-06-25 Fixed erors to make refactored audio work, added audio shield mode to eeprom, added code to test i2c control board
    [AudioRouting.h, TeensySlider.h, main.cpp]
2025-11-14 Altered to use resonant frequencies that have period equal to integer number of sample
2025-12-22 Added Kicad project
    [DEV-15583.step, TXS0108EPWR.step, teensy_max98389.kicad_pcb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]
2025-12-27 Changed sample rate register setting to sense currrent from 10kHz to 20kHz
2026-02-19 Changed audio routing to use custom teensy audio object instead of queues and added audio loopback test
2026-02-25 Fix for voltage and current being wrong way around, added piezo mode (passthrough to USB)
    [AudioRouting.h, main.cpp]
2026-02-26 Added run-time recall of PCB revision and appropriate audio routing
2026-03-18 Initial code to set inductance filtering
2026-05-03 added adc input for accelerometer measurements
2026-07-06 UPVERSION V2.0 (added routing options, i2c control, etc)
